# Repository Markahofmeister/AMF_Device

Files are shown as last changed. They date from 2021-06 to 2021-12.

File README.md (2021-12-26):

### AMF DEVICE

Bluetooth Bactria is an undergraduate biology laboratory at the University of Pittsburgh, researching the extent to which temperature control can be used to aid in gene expression. 

The temperature is controlled through magnetic nanoparticles attached to a biological sample, which are heated and kept at a certain temperature. 

Myself and another student were recruited to build a device capable of emitting an alternating magnetic field (AMF) to heat and maintain the temperature of a biological sample.

The final devide is shown below: 

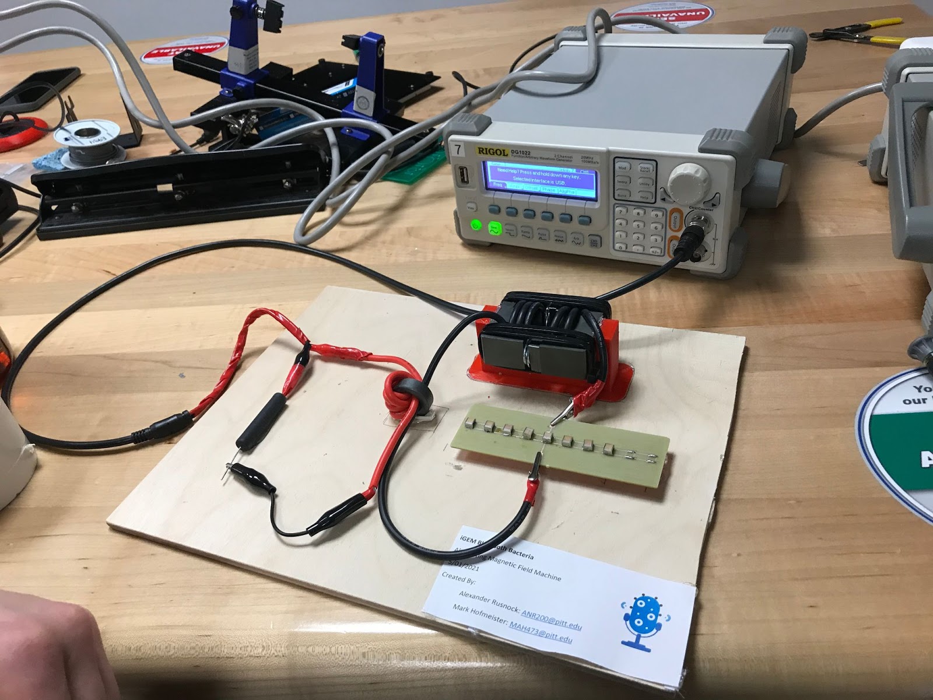
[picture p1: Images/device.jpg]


More information can be found on [my website](https://www.markhofmeister.com/igem-amf-machine-1)

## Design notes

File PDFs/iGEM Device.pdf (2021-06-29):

To use this device, a waveform generator and amplifier will be needed.

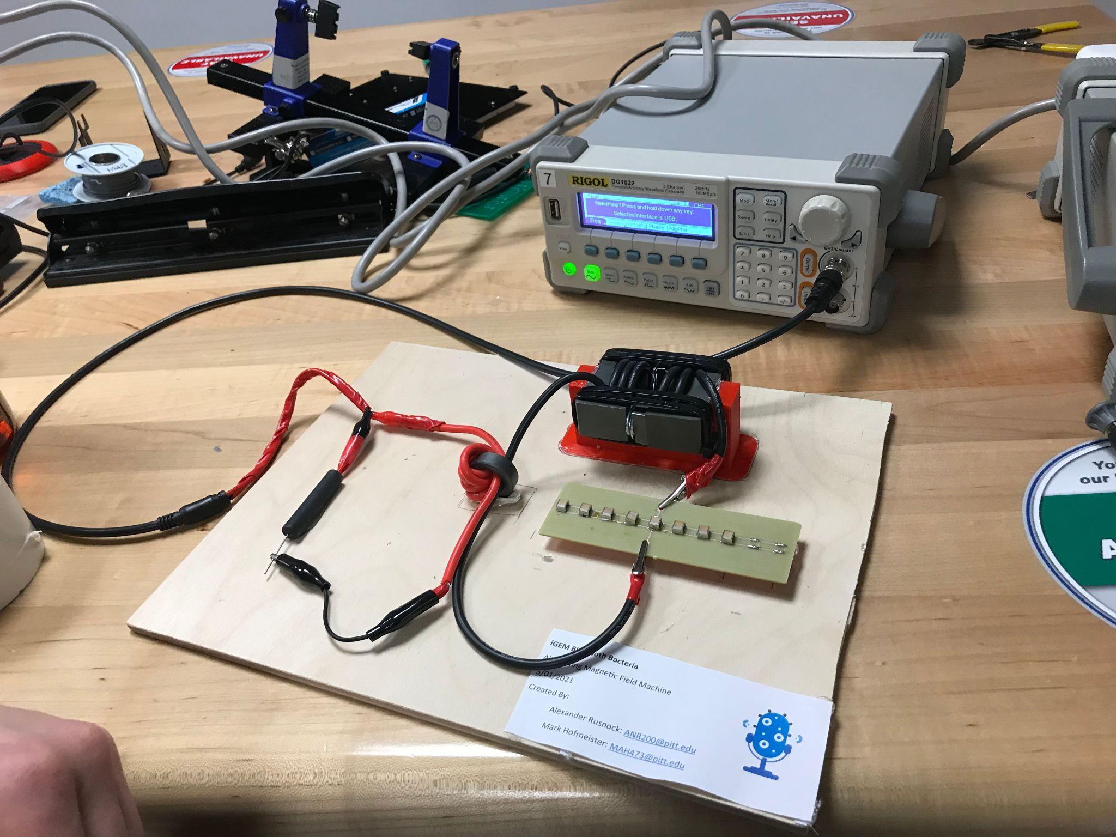
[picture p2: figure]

In the picture above, the coaxial cable (red) is connected directly to a waveform generator. In practice, this coaxial cable will have to be attached to an amplifier capable of the necessary output. This amplifier will then be attached to the waveform generator.

Configure the waveform generator to 20 Vpp and 100-500kHz, depending on laboratory needs.

The exact settings of the amplifier are unknown, as we did not have the device to experiment with.

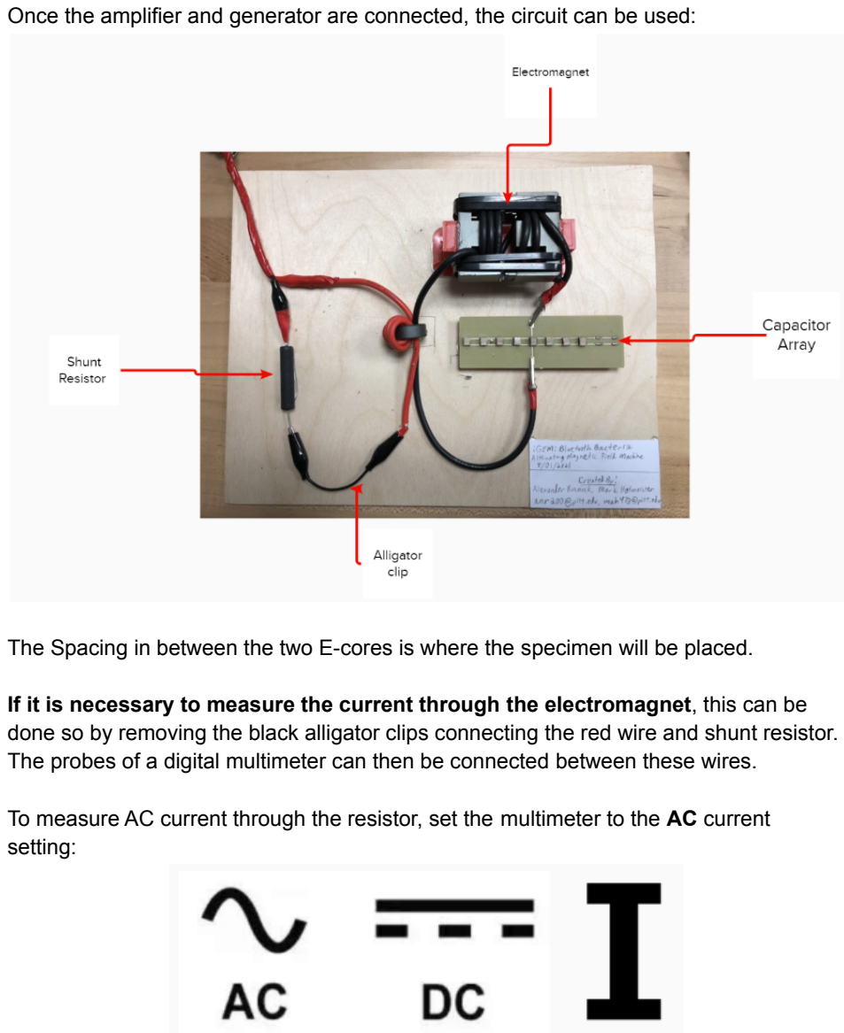
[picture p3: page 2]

Once the amplifier and generator are connected, the circuit can be used:

The Spacing in between the two E-cores is where the specimen will be placed.

If it is necessary to measure the current through the electromagnet, this can be done so by removing the black alligator clips connecting the red wire and shunt resistor. The probes of a digital multimeter can then be connected between these wires.

To measure AC current through the resistor, set the multimeter to the AC current setting:

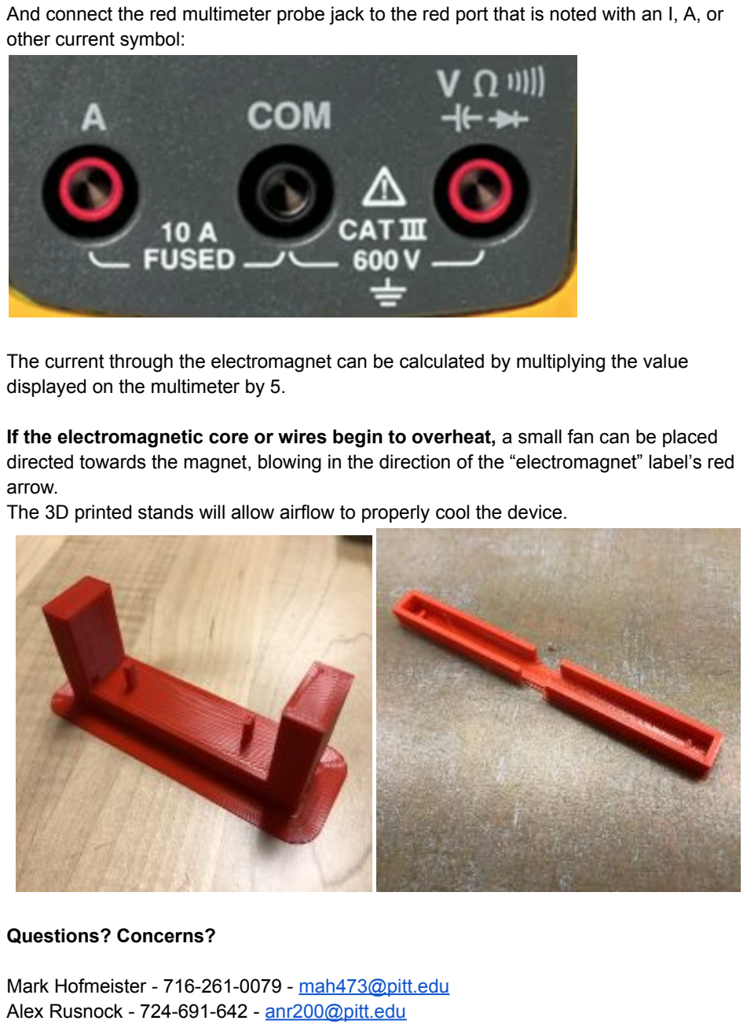
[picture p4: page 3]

And connect the red multimeter probe jack to the red port that is noted with an I, A, or other current symbol:

The current through the electromagnet can be calculated by multiplying the value displayed on the multimeter by 5.

If the electromagnetic core or wires begin to overheat, a small fan can be placed directed towards the magnet, blowing in the direction of the “electromagnet” label’s red arrow.
The 3D printed stands will allow airflow to properly cool the device.

Questions? Concerns?

Mark Hofmeister - 716-261-0079 - mah473@pitt.edu Alex Rusnock - 724-691-642 - anr200@pitt.edu

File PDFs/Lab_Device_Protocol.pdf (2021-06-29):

Equipment and materials you will need

Component | Sub- component | Comments/Link
Amplifier | | The one we used was the 2100L, found here: https://www.eandiltd.com/products/rf-power-amplifiers/
| | These E&I amplifiers are fantastic—they have a lot of built in protection so the only way you can hurt them is by putting in more than 1V.
| | Some places sell these amplifiers used and if you get a lower power, it might be affordable: https://www.bellnw.com/manufacturer/Electronics-and- Innovation/240L-Refurb.htm Also, some places offer a monthly rental https://www.theemcshop.com/dc-220-mhz-rf-amplifiers/649- monthly-rental-ei-eni-2200l-200w-rf-power-amplifier-10-khz- 12-mhz.html
| | I think you might be able to make due with 40W, such as the E&I 240L, and anything more than 100W would be wasteful.

Oscilloscope and function

generator | | One option is to borrow good equipment from your friends in the electrical engineering department. Another is to play around with Bitscopes as waveform generators and scopes: https://bitscope.com/
| | If you’re fans of MATLAB, you might like https://www.digikey.com/product-detail/en/digilent-inc/410- 321/1286-1117-ND/5810115
Electromagnet | Core | Rather than a gapped toroid, I now recommend a different geometry with E cores: https://www.digikey.com/product-detail/en/tdk-electronics- inc/B66375G0000X187/495-5493-ND/3914860 (Other geometries are available in TDK N87 material if you want, especially smaller E cores like this one https://www.digikey.com/product-detail/en/tdk-electronics- inc/B66335G0000X187/495-5441-ND/3914763 a smaller one would require less power and dissipate heat a little more efficently) Then you stack little pieces like these on either side to the thickness you want https://www.digikey.com/product-detail/en/tdk-electronics- inc/B66483P0000X187/495-75529-ND/3915025
| | You might need to 3D print or laser cut a frame to hold it together

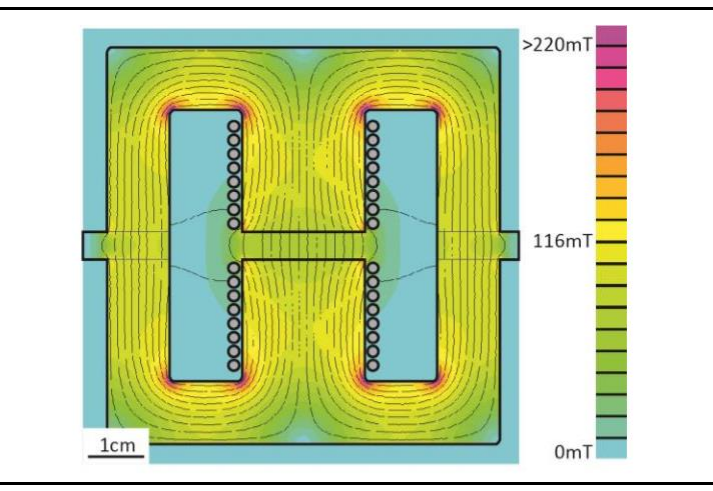
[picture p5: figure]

Wire | We used Litz wire custom made for us from MWS, but I do not think this is really necessary because at high amplitudes, the losses are dominated by the core. Moreover, it can be a bit difficult to solder properly and the technique is different from soldering almost anything else—not a great way to learn if it is new for you. I would recommend something around 12 AWG and try something cheap first: https://www.digikey.com/product-detail/en/nte-electronics- inc/WH612-06-25/2368-WH612-06-25-ND/11655551 Consider getting silicone tubing as an extra outer layer precaution for the wires going between the coil and the capacitor https://www.mcmaster.com/silicone-rubber-tubing
Capacitors | Capacitor selection is pretty important for making this work properly, but there is some wiggle room. Essentially, you ideally want capacitors that are “High Q” or “Low loss” RF capacitors. It is usually cheapest to make an array of these capacitors to handle the current and the voltage. I wrote a lot about designing the array in the tutorial, so look there and don’t be afraid to run a selection by me if you want to check. My two favorite options are the following: • Surface mount mica capacitors (excellent stability, very high Q) Here is an example: https://www.digikey.ch/product-detail/en/cornell- dubilier-electronics-cde/MC22FF152J-TF/338-4455-2- ND/1921772 • Surface mount ceramic capacitors with X7R dielectric material or C0G, NP0 dielectric typically work well if you make an array with a lot of them in parallel. They drift a little bit more than the mica ones during operation, but with a field probe or shunt you can characterize your field vs time and make sure you’re getting what you want.
Vector board (for laying out array) | https://www.digikey.com/products/en?keywords=169P44WEC1 Basically you have to cut out a shape with shears and then scrape away the copper, e.g. with a Deremel tool where you don’t need it.

| | If you want operation at a fixed frequency, I don’t think you need to make complicated connectors. Instead you can just solder directly to the array
| Box | See instructions and drawings for making a box in the tutorial if you want https://www.mcmaster.com/acrylic-plastic Otherwise there are lots of commercially available plastic enclosures https://www.digikey.com/products/en/boxes-enclosures-racks/boxes/594
Transformer | Core | These are easy to make for this kind of application. https://www.digikey.com/product-detail/en/tdk-electronics-inc/B64290L0082X087/495-3872-ND/1830202
| Wire | Again litz wire would be ideal, but you should try first with the same 12 AWG wire you use for the coil
| BNC connector | https://www.digikey.ch/product-detail/en/adam-tech/RF1-08-D-00-50-HDW/2057-RF1-08-D-00-50-HDW-ND/9830966
Shunt resistor | Enclosure | See above for capacitor
| Resistor | The value depends on where you choose to put it in the circuit. If it’s going to handle a lot of current, you want to keep its resistance small, but you do want a measurable voltage Here’s a 0.1 Ohm option https://www.digikey.ch/product-detail/en/ohmite/TGHDXR100JE/273-TGHDXR100JE-ND/10441427 And a 1 Ohm option https://www.digikey.ch/product-detail/en/ohmite/TGHDX1R00JE/273-TGHDX1R00JE-ND/10441444 I think a heat sink is not needed for these above, since you should be dissipating <<100 watts in them if designed properly
Field probe | Wire | This needs to be very small wire. If you use thick wire, eddy currents will probably cause it to catch fire, or so was my experience. https://www.digikey.ch/product-detail/en/belden-inc/8055/BEL1983-ND/7389416 Small magnet wire is unfortunately a bit expensive, but I think you can shop around for a cheaper source than this above. If you’re really having trouble, I can put a little bit of small Litz wire in an envelope and send it to you
| Form | I suggest you 3D print a suitable design

Process I would follow to make a suitable setup

1) Wind the turns on your inductor, make a frame to hold it together, including the spacers on each side.
2) Measure the inductance of your electromagnet. (Some multimeters have an inductance measurement function, your friends in the EE department might have access to a proper LCR meter, or you can test resonance using some known capacitances with your fn generator/scope combo)
3) Design your capacitor to resonate appropriately with the inductor and lay out the rest of the circuit:
a. Make your transformer, remembering that in this case the secondary has fewer turns than the primary so that you can step up current. Maybe start with a 5:1 ratio, a good guess for these circuits in my experience
b. You might consider incorporating your shunt resistorright into the transformer box if there is space
4) Test resonance of your coil, monitoring the supplied current with the shunt resistor
5) Make adjustments as needed. This includes:
a. Modifying the capacitor array to get the right resonance
b. Changing the winding ratio on the transformer to optimize power transfer. (The amplifiers I recommended indicate values for power that is “reflected” and delivered. You want to adjust the transformerratio to make the delivered power as large as possible and the reflected power as small as possible.
6) Use a field probe designed to sit in the same spot as your sample to study performance under the conditions you are interested in.

Misc

- I would recommend 500 kHz operation rather than 100 kHz since this is near where the H*f product of the material peaks
- There are lots of ways to incorporate a shunt. I recommend keeping ti out of the high current part of the circuit if you can

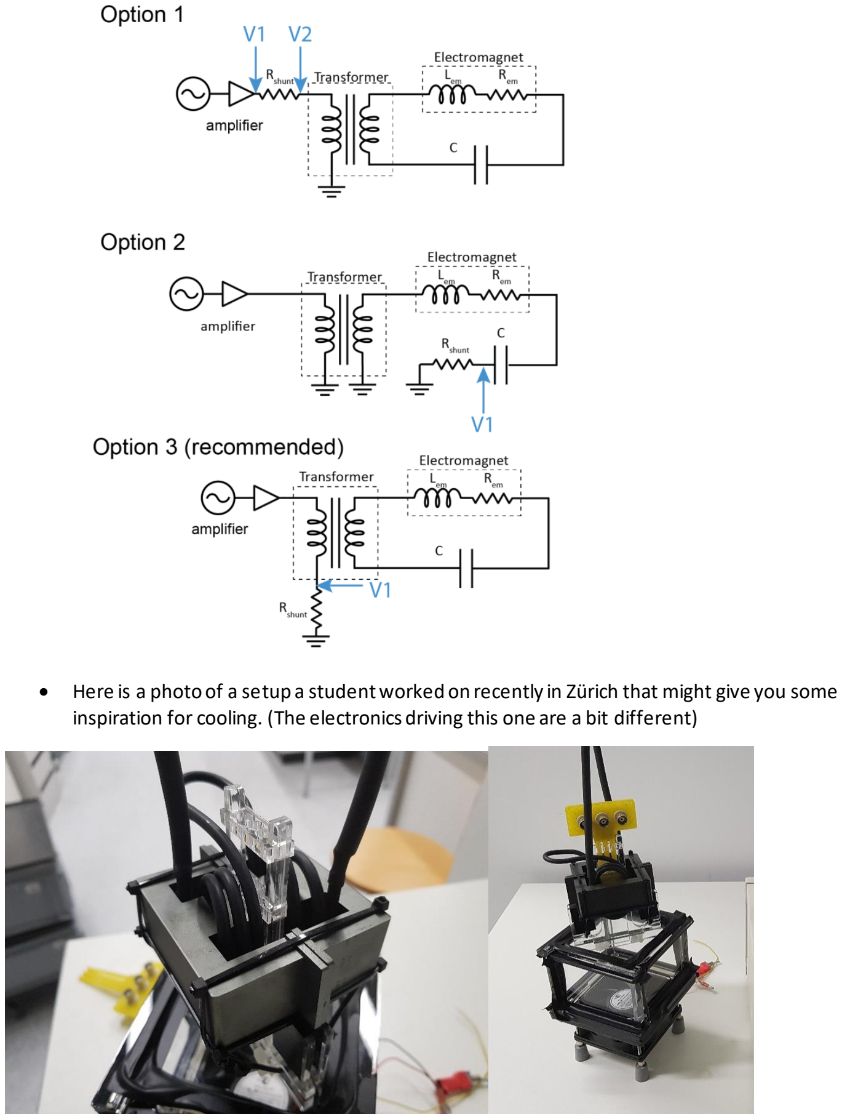
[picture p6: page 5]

- Here is a photo of a setup a student worked on recently in Zürich that might give you some inspiration for cooling. (The electronics driving this one are a bit different)

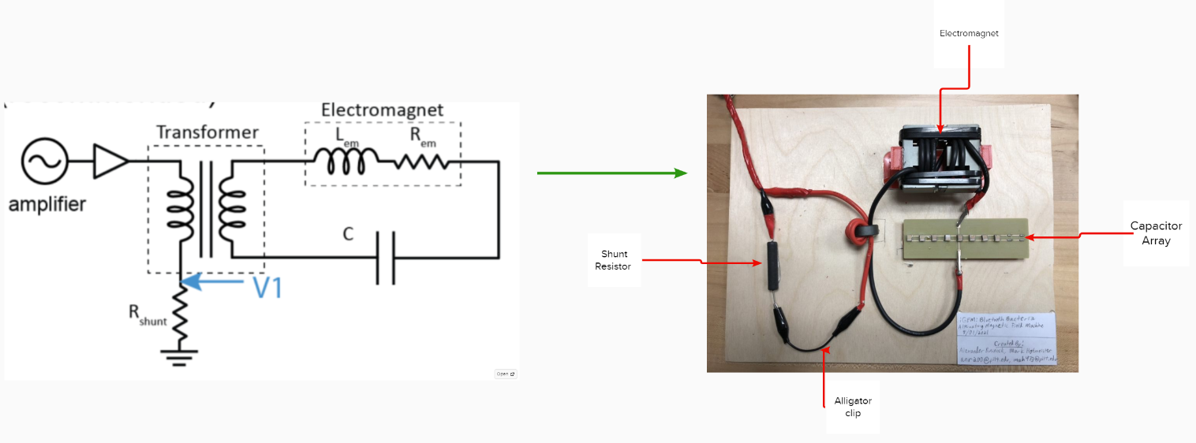
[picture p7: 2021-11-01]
Images/Schematic_to_Device.png

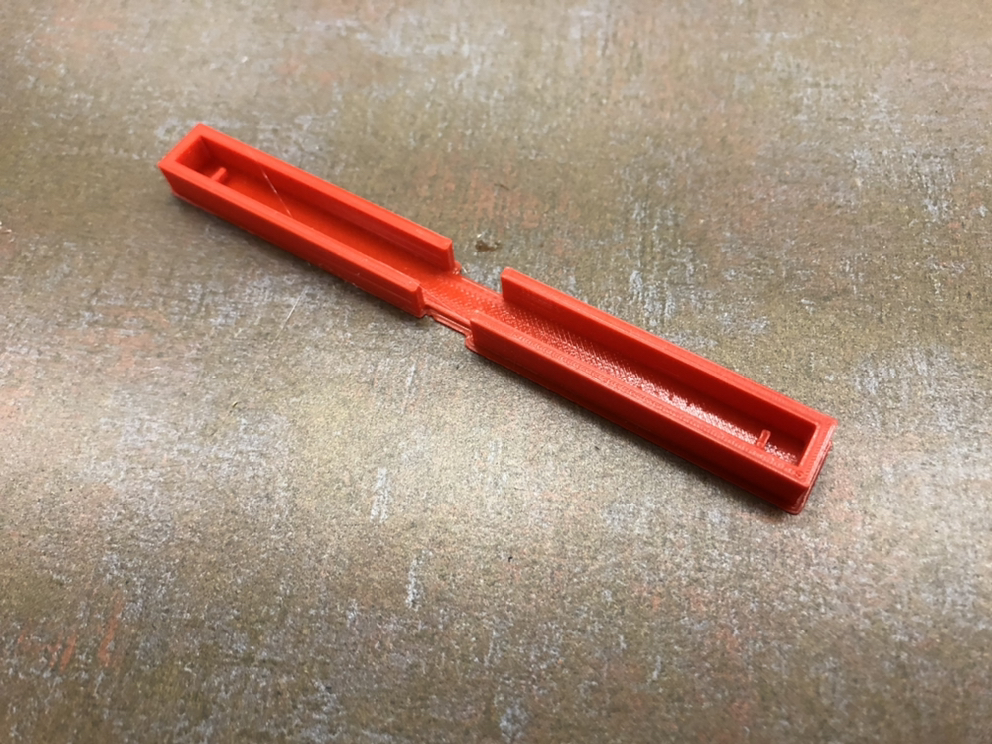
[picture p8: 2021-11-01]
Images/Capacitor_Cooling.jpeg

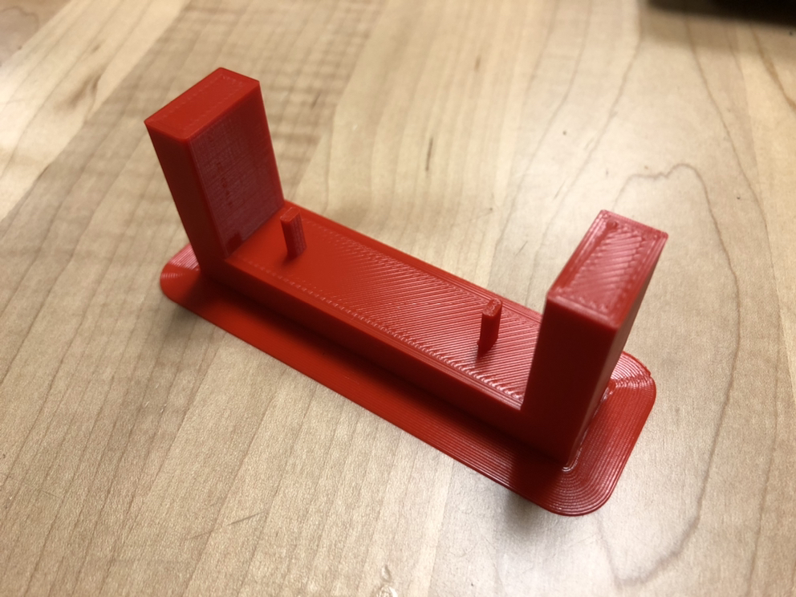
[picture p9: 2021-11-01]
Images/Magnet_Cooling.jpeg

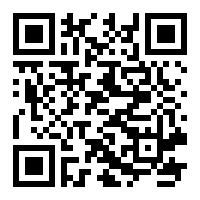
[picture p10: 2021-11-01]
Images/iGEM_QR.png

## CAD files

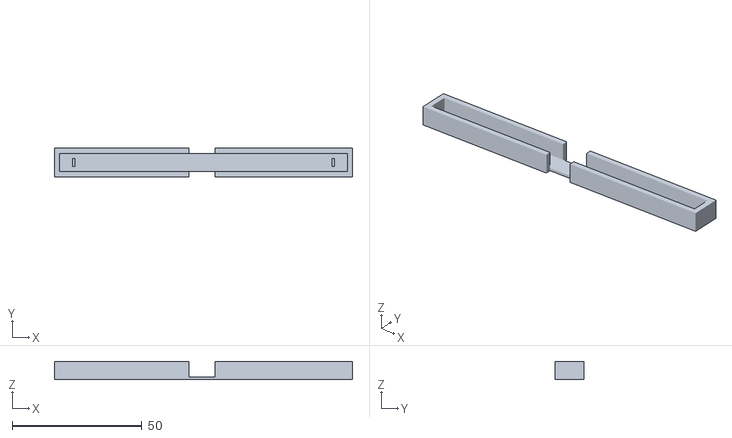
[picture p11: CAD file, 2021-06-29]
STL_Files/Capacitor_Array.stl
115.0 x 11.0 x 7.00

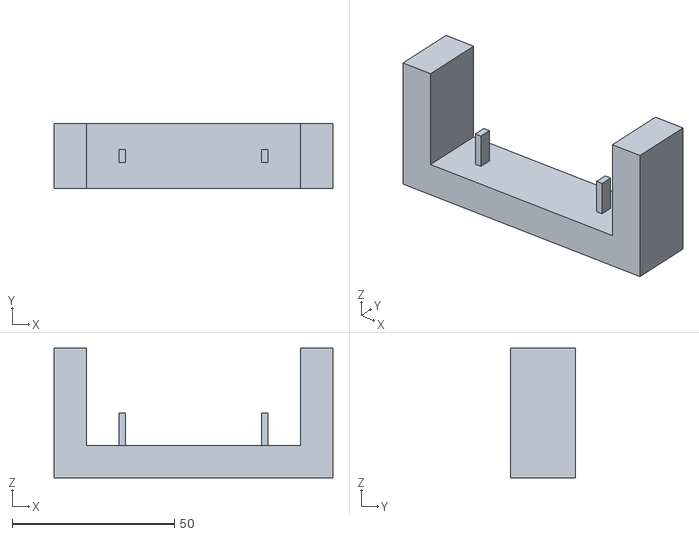
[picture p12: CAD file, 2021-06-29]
STL_Files/Magnet_Stand.stl
86.0 x 20.0 x 40.0

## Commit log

2021-06-29 File Commits
    [Capacitor_Array.stl, Magnet_Stand.stl]
2021-06-29 File Organization
    [Capacitor_Array.stl, Magnet_Stand.stl]
2021-10-28 [ImgBot] Optimize images
    *Total -- 1,941.47kb -> 1,760.03kb (9.35%)
    /Images/iGEM_QR.png -- 3.39kb -> 0.59kb (82.73%)
    /Images/Schematic_to_Device.png -- 351.82kb -> 296.00kb (15.87%)
    /Images/Capacitor_Cooling.jpeg -- 727.68kb -> 655.15kb (9.97%)
    /Images/Magnet_Cooling.jpeg -- 551.24kb -> 506.82kb (8.06%)
    /Images/device.jpg -- 307.33kb -> 301.47kb (1.91%)
